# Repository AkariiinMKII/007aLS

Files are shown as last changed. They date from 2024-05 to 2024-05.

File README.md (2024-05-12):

# 007_a_L(onely)_S(pace)

A custom keyboard based on STM32F103 and QMK, with only a space bar, but expandable.








## Hardware

### PCB

See files in [PCB](./PCB).

[EasyEDA Pro](https://pro.easyeda.com/editor) is needed to edit `.epro` file.

### 3D printed Case

See files in [Case](./Case).

### Parts to purchase (in Chinese only)

_All of these should be available in China Mainland._

|内容|数量|备注|链接|
|-|:-:|-|-|
|M2\*17mm 六角铜柱|4|外壳固定用|<https://detail.tmall.com/item.htm?id=644381840317>|
|M2\*7mm 扁头螺丝 头部直径6mm|8|外壳固定用，一端拧上后卡入上盖|<https://detail.tmall.com/item.htm?id=718532926918>|
|M2\*3mm 扁头螺丝|4|定位板固定用|<https://detail.tmall.com/item.htm?id=13836098491>|
|M2\*3.5mm 六角铜柱|2|定位板固定用|<https://item.taobao.com/item.htm?id=743158489039>|
|M2绝缘垫片 直径4mm 厚0.5mm|2|定位板固定用，用于PCB下方|<https://detail.tmall.com/item.htm?id=535558533487>|
|M2对锁螺丝 母钉螺杆4mm 外直径3mm|2|小板固定用 [\*1]，母钉用于小板上方|<https://detail.tmall.com/item.htm?id=616768747669>|
|M3绝缘垫片 直径6mm 厚0.5mm|2|小板固定用，用于小板上方|<https://detail.tmall.com/item.htm?id=535558533487>|
|13x4x2.5mm 圆头脚垫|4||<https://item.taobao.com/item.htm?id=579251575258>|
|FPC排线 4pin 间隔0.5mm 长度70mm 同向|1||<https://item.taobao.com/item.htm?id=616354301362>|

*1: 如对外观有要求可购买外壳螺丝同款的 M2\*3 扁头螺丝代替原有螺丝

## Firmware

See files in [Firmware](./Firmware).

### Bootloader

[STM32duino](https://github.com/rogerclarkmelbourne/STM32duino-bootloader/blob/master/bootloader_only_binaries/generic-none_bootloader.bin)

### QMK

Added in this [commit](https://github.com/AkariiinMKII/qmk_firmware/commit/17e1cea3b4afec91959c45b3cf8241e8540ba4bb).

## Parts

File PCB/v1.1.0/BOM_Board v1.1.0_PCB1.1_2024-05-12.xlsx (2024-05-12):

No. | Quantity | Comment | Designator | Footprint | Value | Manufacturer Part | Manufacturer | Supplier Part | Supplier
1 | 5 | 100nF | C1,C4,C5,C6,C7 | C0603 | 100nF | CC0603KRX7R9BB104 | YAGEO(国巨) | C14663 | LCSC
2 | 2 | 22pF | C2,C3 | C0603 | 22pF | CL10C220JB8NNNC | SAMSUNG(三星) | C1653 | LCSC
3 | 2 | 1uF | C8,C9 | C0603 | 1uF | CL10A105KB8NNNC | SAMSUNG(三星) | C15849 | LCSC
4 | 1 | 1N4148WS | D1 | SOD-323_L1.8-W1.3-LS2.5-RD |  | 1N4148WS | CJ(江苏长电/长晶) | C2128 | LCSC
5 | 2 | AFC04-S04FCA-00 | FPC3,FPC4 | FPC-SMD_AFC04-S04FCA-00 |  | AFC04-S04FCA-00 | JS(钜硕电子) | C883623 | LCSC
6 | 1 | THD0515-30CL-SN | FPC5 | FFC-SMD_30P-P0.50_THD0515-30CL-SN |  | THD0515-30CL-SN | THD(台华达) | C283152 | LCSC
7 | 1 | PZ254V-11-04P | H1 | HDR-TH_4P-P2.54-V-M |  | PZ254V-11-04P | XFCN(兴飞) | C2691448 | LCSC
8 | 3 | 10kΩ | R1,R2,R3 | R0603 | 10kΩ | 0603WAF1002T5E | UNI-ROYAL(厚声) | C25804 | LCSC
9 | 2 | 22Ω | R4,R5 | R0603 | 22Ω | 0603WAF220JT5E | UNI-ROYAL(厚声) | C23345 | LCSC
10 | 1 | 4.7kΩ | R6 | R0603 | 4.7kΩ | 0603WAF4701T5E | UNI-ROYAL(厚声) | C23162 | LCSC
11 | 2 | 5.1kΩ | R7,R8 | R0603 | 5.1kΩ | 0603WAF5101T5E | UNI-ROYAL(厚声) | C23186 | LCSC
12 | 1 | 1TS026A-2300-0553-CT | SW1 | SW-SMD_4P-L2.6-W1.6-P0.75-LS3.0 |  | 1TS026A-2300-0553-CT | HYP(鸿源精密) | C913791 | LCSC
13 | 1 | MXOnly-6.25U/7U-Hotswap-ReversedStabilizers | U1 | MXOnly-6.25U/7U-Hotswap-ReversedStabilizers
14 | 1 | STM32F103C8T6 | U2 | LQFP-48_L7.0-W7.0-P0.50-LS9.0-BL |  | STM32F103C8T6 | ST(意法半导体) | C8734 | LCSC
15 | 1 | XC6206P332MR-G | U3 | SOT-23-3_L2.9-W1.6-P1.90-LS2.8-BR |  | XC6206P332MR-G | TOREX(特瑞仕) | C5446 | LCSC
16 | 1 | KH-TYPE-C-16P | USB1 | USB-C-SMD_KH-TYPE-C-16P |  | KH-TYPE-C-16P | kinghelm(金航标) | C709357 | LCSC
17 | 1 | 8MHz | X3 | OSC-SMD_4P-L3.2-W2.5-BL | 8MHz | TAXM8M4RDBCCT2T | YJX(雅晶鑫) | C400090 | LCSC

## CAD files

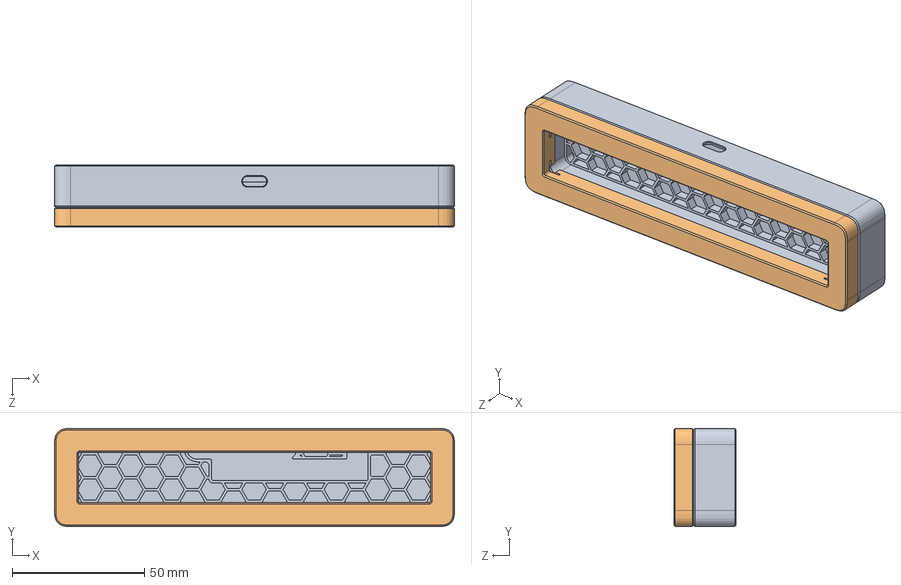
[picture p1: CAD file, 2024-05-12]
Case/v1.1.0/case.SLDASM
151.0 x 37.0 x 23.6 mm
bottom
top

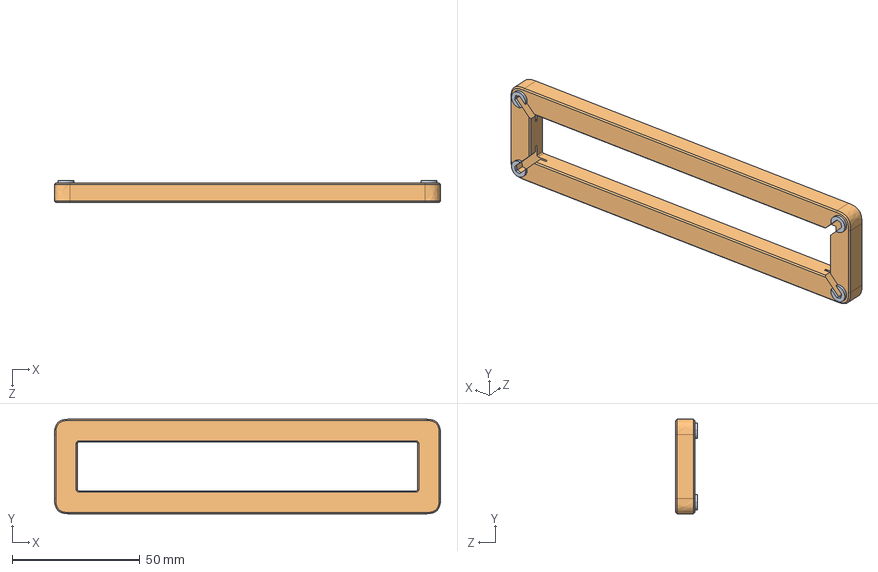
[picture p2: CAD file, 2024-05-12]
Case/v1.1.0/top.STEP
151.0 x 37.0 x 8.50 mm

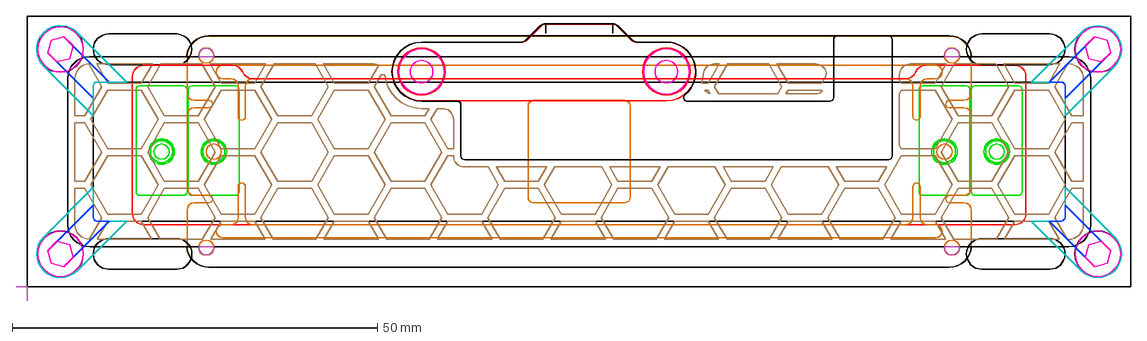
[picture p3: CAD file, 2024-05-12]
Misc/draft1.1.0.dxf
152.5 x 38.9 mm

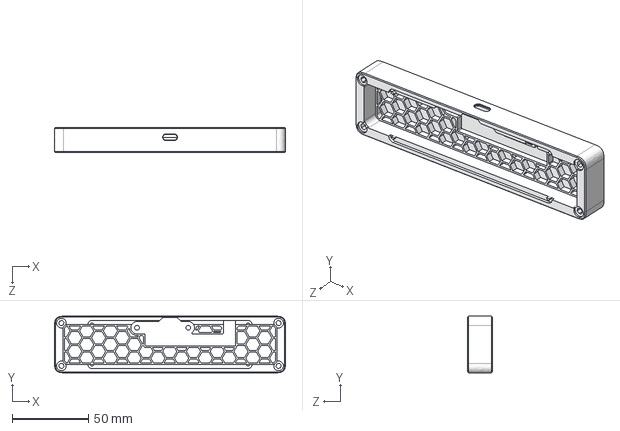
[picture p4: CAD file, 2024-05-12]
Case/v1.1.0/bottom.STEP
151.0 x 37.0 x 16.1 mm

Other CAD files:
Case/v1.1.0/bottom.SLDPRT
Case/v1.1.0/bottom.STL
Case/v1.1.0/top.SLDPRT
Case/v1.1.0/top.STL
